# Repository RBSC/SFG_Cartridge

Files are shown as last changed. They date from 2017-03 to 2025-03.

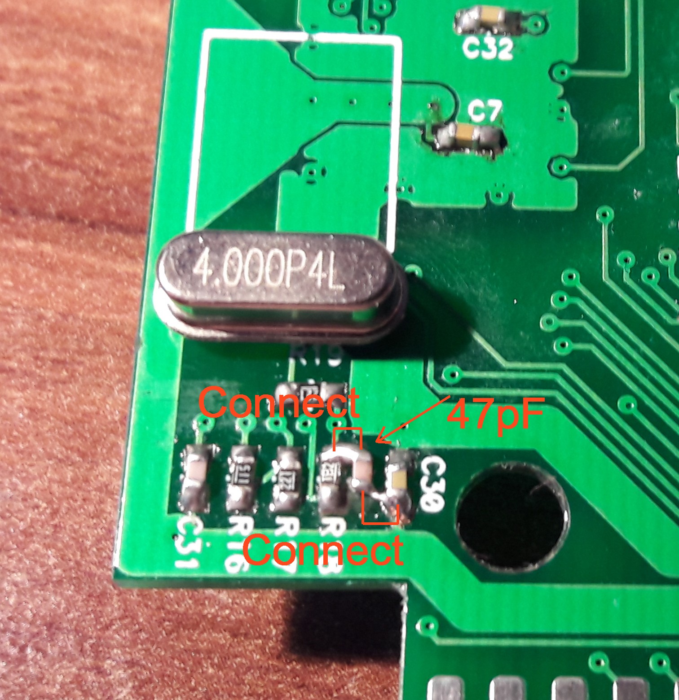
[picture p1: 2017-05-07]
Pics/74HCT04_fix_cart.jpg

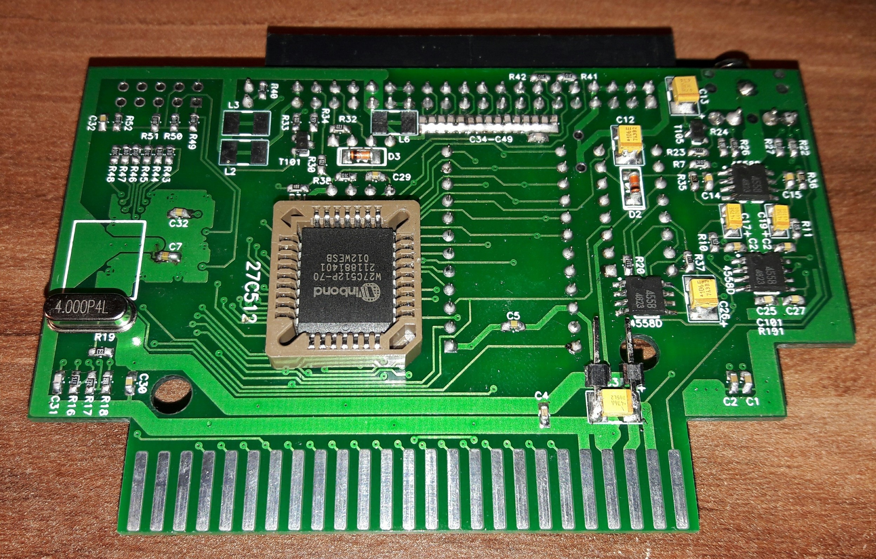
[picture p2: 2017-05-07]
Pics/assembled_cart_back.jpg

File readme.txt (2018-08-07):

Yamaha SFG 05/01-S Cartridge Board v1.2
Copyright (c) 2017 RBSC

The Setup
---------

After assembling, the cartridge needs to be programmed in order to function properly. The following steps are necessary:

 1. Upload the Altera's firmware
 2. Program the BIOS with the provided ROM file

How to upload the firmware
--------------------------

The below instructions are for programming the Altera chip.

 1. Solder jumper pins both sides of C3 capacitor (only for older boards without power connector)
 2. Prepare the ByteBlaster 2 programmer, open the Quartus II software, keep default JTAG selection
 3. Supply 5v power to the cartridge board via jumper pins (mind the correct polarity!)
 4. Connect the ByteBlaster's cable to the AS socket of the cartridge (make sure you connect the cable correctly!)
 5. Click "Autodetect" in Quartus II software, the Altera chip should be found and ready for programming
 6. Use "Change file" option and select the .POF file from the "Firmware" directory
 7. Enable the checkboxes: "Program/Configure", "Verify" and "Blank Check"
 8. Click "Start" and monitor the programming and verification process

If the programming completed successfully, disconnect the ByteBlaster's cable and 5v power from the board.

You must also write the provided ROM file from BIOS directory into the W27C512 EEPROM chip (PLCC32) using any EEPROM programmer.
The ROM file contains 2 different BIOS versions that can be selected by the special jumper on the board.

Using the extension board
-------------------------

The separate extension board was created for the SFG cartridge in order to make available standard SFG sockets - left and right
RCA audio sockets, music keyboard socked and MIDI IN and MIDI OUT sockets. The board can be either mounted on top of the
cartridge or it can be connected to the cartridge with the standard IDE ribbon cable.

IMPORTANT! When connecting the ribbon cable or plugging the extension board on top of the cartridge please make sure that you are
connecting correctly, otherwise damage may occur to your SFG cartridge!

Starting SFG BIOS
-----------------

To start the built-in SFG BIOS make sure that Basic is loaded and type "_musica" or "call musica" without quotes and press Enter.
The BIOS should start immediately. Depending on whether the jumper is installed or not, either the SFG-01 BIOS or SFG-05 BIOS will
be launched. To exit from BIOS software just reboot your MSX.

Notes
-----

If you are using 74HCT04 chip instead of 74LS04 please make sure you add one additional 47pf capacitor. See the 74HCT04_fix_cart.jpg
image for capacitor mounting instructions. This picture shows the placing of an additional capacitor on the board version 1.0. Later
versions of the board have the dedicated place for this capacitor (C50).

IMPORTANT!
----------

The RBSC provides all the files and information for free, without any liability (see the disclaimer.txt file). The provided information,
software or hardware must not be used for commercial purposes unless permitted by the RBSC. Producing a small amount of bare boards for
personal projects and selling the rest of the batch is allowed without the permission of RBSC.

When the sources of the tools are used to create alternative projects, please always mention the original source and the copyright!

Contact information
-------------------

The members of RBSC group Wierzbowsky, Ptero and DJS3000 can be contacted via the MSX.ORG or ZX-PK.RU forums. Just send a personal
message and state your business.

The RBSC repository can be found here:

https://github.com/rbsc

-= ! MSX FOREVER ! =-

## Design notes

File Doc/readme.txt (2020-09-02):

Yamaha SFG 05/01-S Cartridge Board v1.2
Copyright (c) 2017-2020 RBSC

The Setup
---------

After assembling, the cartridge needs to be programmed in order to function properly. The following steps are necessary:

 1. Upload the Altera's firmware
 2. Program the BIOS with the provided ROM file

How to upload the firmware
--------------------------

The below instructions are for programming the Altera chip.

 1. Solder jumper pins both sides of C3 capacitor (only for older boards without power connector)
 2. Prepare the ByteBlaster 2 programmer, open the Quartus II software, keep default JTAG selection
 3. Supply 5v power to the cartridge board via jumper pins (mind the correct polarity!)
 4. Connect the ByteBlaster's cable to the AS socket of the cartridge (make sure you connect the cable correctly!)
 5. Click "Autodetect" in Quartus II software, the Altera chip should be found and ready for programming
 6. Use "Change file" option and select the .POF file from the "Firmware" directory
 7. Enable the checkboxes: "Program/Configure", "Verify" and "Blank Check"
 8. Click "Start" and monitor the programming and verification process

If the programming completed successfully, disconnect the ByteBlaster's cable and 5v power from the board.

You must also write the provided ROM file from BIOS directory into the W27C512 EEPROM chip (PLCC32) using any EEPROM programmer.
The ROM file contains 2 different BIOS versions that can be selected by the special jumper on the board.

Using the extension board
-------------------------

The separate extension board was created for the SFG cartridge in order to make available standard SFG sockets - left and right
RCA audio sockets, music keyboard socked and MIDI IN and MIDI OUT sockets. The board can be either mounted on top of the
cartridge or it can be connected to the cartridge with the standard IDE ribbon cable.

IMPORTANT! When connecting the ribbon cable or plugging the extension board on top of the cartridge please make sure that you are
connecting correctly, otherwise damage may occur to your SFG cartridge!

Starting SFG BIOS
-----------------

To start the built-in SFG BIOS make sure that Basic is loaded and type "_musica" or "call musica" without quotes and press Enter.
The BIOS should start immediately. Depending on whether the jumper is installed or not, either the SFG-01 BIOS or SFG-05 BIOS will
be launched. To exit from BIOS software just reboot your MSX.

Notes
-----

If you are using 74HCT04 chip instead of 74LS04 please make sure you add one additional 47pf capacitor. See the 74HCT04_fix_cart.jpg
image for capacitor mounting instructions. This picture shows the placing of an additional capacitor on the board version 1.0. Later
versions of the board have the dedicated place for this capacitor (C50).

IMPORTANT!
----------

The RBSC provides all the files and information for free, without any liability (see the disclaimer.txt file). The provided information,
software or hardware must not be used for commercial purposes unless permitted by the RBSC. Producing a small amount of bare boards for
personal projects and selling the rest of the batch is allowed without the permission of RBSC.

When the sources of the tools are used to create alternative projects, please always mention the original source and the copyright!

Contact information
-------------------

The members of RBSC group Tnt23, Wierzbowsky, Pencioner, Ptero, GreyWolf, SuperMax and DJS3000 can be contacted via the group's e-mail
address:

info@rbsc.su

The group's coordinator could be reached via this e-mail address:

admin@rbsc.su

The group's website can be found here:

https://rbsc.su/
https://rbsc.su/ru

The RBSC's hardware repository can be found here:

https://github.com/rbsc

The RBSC's 3D model repository can be found here:

https://www.thingiverse.com/groups/rbsc/things

-= ! MSX FOREVER ! =-

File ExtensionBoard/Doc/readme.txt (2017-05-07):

Yamaha SFG 05/01-S Cartridge Extension Board v1.0
Copyright (c) 2017 RBSC

About
-----

The separate extension board was created for the SFG cartridge in order to make available standard SFG sockets - left and right
RCA audio sockets, music keyboard socked and MIDI IN and MIDI OUT sockets. The board can be either mounted on top of the
cartridge or it can be connected to the cartridge with the standard IDE ribbon cable.

IMPORTANT! When connecting the ribbon cable or plugging the extension board on top of the cartridge please make sure that you are
connecting correctly, otherwise damage may occur to your SFG cartridge! Don't solder the straight pin male IDE connector to the
place where the IDE angled pin female connector should be soldered. The pins of those 2 connectors are vertically reversed! The
IDE ribbon cable must be connected only to the straight pin male connector on the extension board.

IMPORTANT!
----------

The RBSC provides all the files and information for free, without any liability (see the disclaimer.txt file). The provided information,
software or hardware must not be used for commercial purposes unless permitted by the RBSC. Producing a small amount of bare boards for
personal projects and selling the rest of the batch is allowed without the permission of RBSC.

When the sources of the tools are used to create alternative projects, please always mention the original source and the copyright!

Contact information
-------------------

The members of RBSC group Wierzbowsky, Ptero and DJS3000 can be contacted via the MSX.ORG or ZX-PK.RU forums. Just send a personal
message and state your business.

The RBSC repository can be found here:

https://github.com/rbsc

-= ! MSX FOREVER ! =-

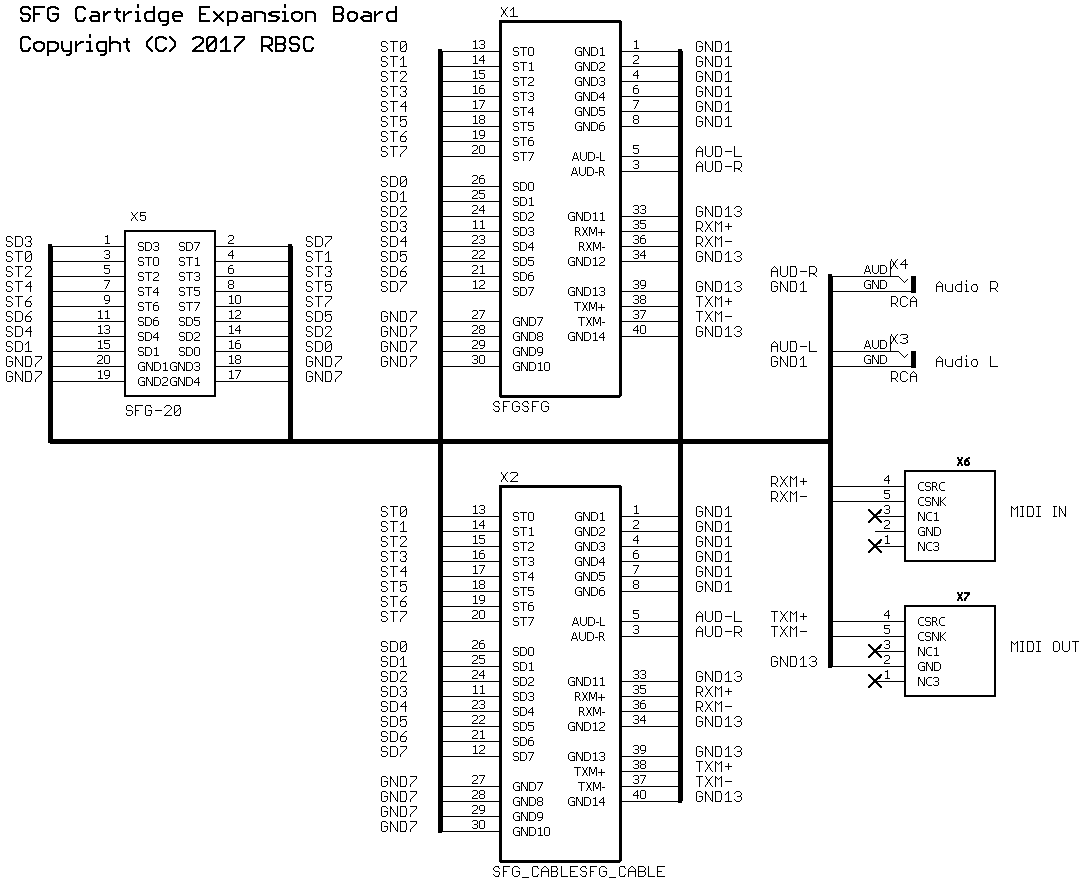
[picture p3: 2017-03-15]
ExtensionBoard/Doc/schematics.png

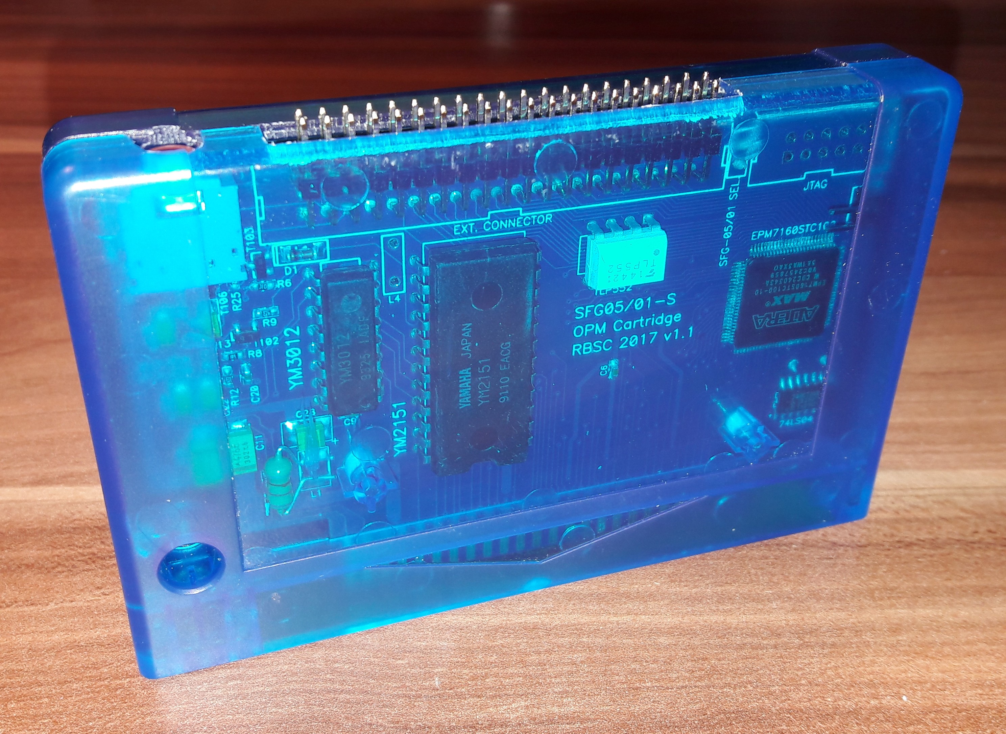
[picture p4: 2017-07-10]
Pics/cart_case.jpg

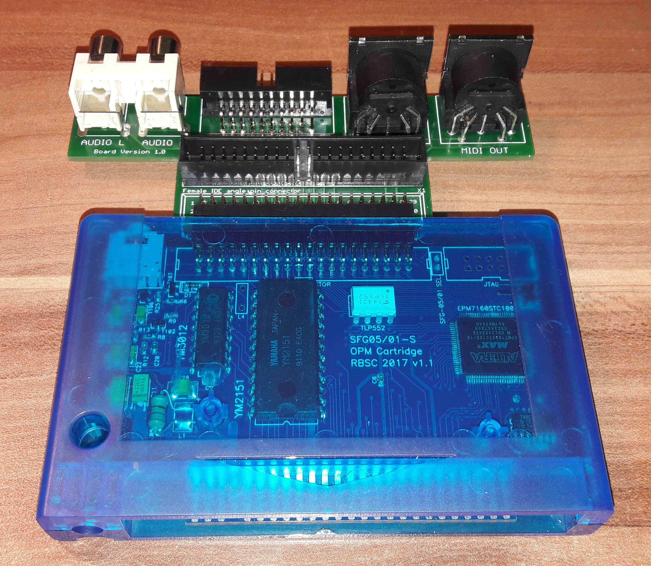
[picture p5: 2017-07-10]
Pics/cart_with_adapter.jpg

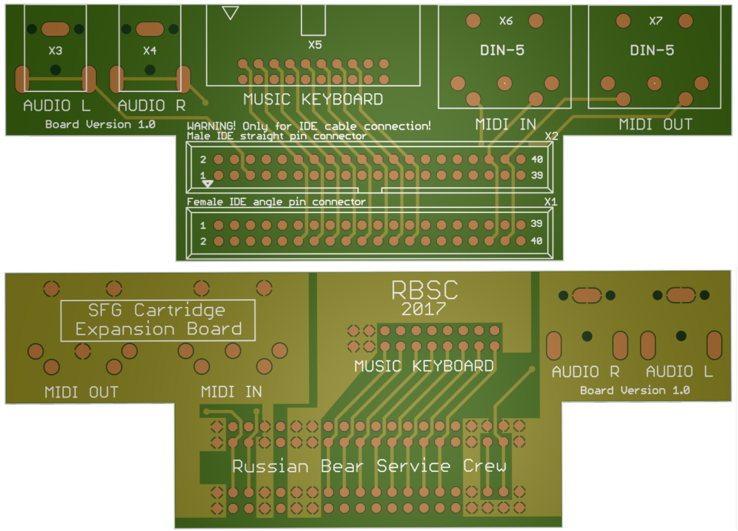
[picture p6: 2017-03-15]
ExtensionBoard/Pics/board.jpg

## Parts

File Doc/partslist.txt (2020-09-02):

SFG 05/01-S OPM Cartridge Version 1.2
Copyright (C) 2017-2020 RBSC
Original SFG design by Yamaha Corp.

IMPORTANT!
On the board version 1.0 (on this board the version number may be missing) the R34 and R33 resistors' numbers
are swapped. So the 220 Ohm resistor should be must on the pads marked as R34 and the 4.7 kOhm resistor must
be soldered on the pads marked as R33.

Partslist
---------

Count  ComponentName   RefDes          PatternName     Value           Notes
------ --------------- --------------- --------------- --------------- ---------------

     3 1N4148S         D1              SOD80PD                         SMD diode
                       D2                                                                             
                       D3                                                                             
     3 4558D           AU1             SOP8                            Amplifier
                       AU2                                                                            
                       AU3                                                                            
     1 C_0603          C20             C0603_132A      0.027           
    11 C_0603          C1              C0603_132A      0.1             
                       C2                                                                             
                       C4                                                                             
                       C5                                                                             
                       C6                                                                             
                       C7                                                                             
                       C9                                                                             
                       C29                                                                            
                       C30                                                                            
                       C32                                                                            
                       C33                                                                            
     2 C_0603          C25             C0603_132A      1n              
                       C27                                                                            
     2 C_0603          C21             C0603_132A      1n8             
                       C23                                                                            
     1 C_0603          C50             C0603_132A      47pF             Only for 74HCT04 option!
    17 C_0603          C31             C0603_132A      100pF            
                       C34                                                                            
                       C35                                                                            
                       C36                                                                            
                       C37                                                                            
                       C38                                                                            
                       C39                                                                            
                       C40                                                                            
                       C41                                                                            
                       C42                                                                            
                       C43                                                                            
                       C44                                                                            
                       C45                                                                            
                       C46                                                                            
                       C47                                                                            
                       C48                                                                            
                       C49                                                                            
     2 C_0603          C14             C0603_132A      390pF            
                       C15                                                                            
     6 C_1206          C16             C1206_134A      4.7uF 25v       
                       C17                                                                            
                       C18                                                                            
                       C19                                                                            
                       C22                                                                            
                       C24                                                                            
     1 C_1812          C12             C1812_136A      10uF 6.3v       
     1 C_1812          C26             C1812_136A      10uF 16v        
     2 C_1812          C3              C1812_136A      47uF 16v        
                       C28                                                                            
     1 C_1812          C13             C1812_136A      47uF 6.3v      
     1 C_1812          L1              C1812_136A      820 uH          Power filter, must-have
     4 C_1812          L2              C1812_136A                      Optional ferrite bead
                       L3                                              Optional ferrite bead
                       L4                                              Optional ferrite bead
                       L5                                              Optional ferrite bead
     1 EPM7160STC100-1 IC103           TQFP100                         Altera MAX
     1 IDC2X20M        CN4             IDC40M                          Angled male IDE connector
     1 IDC10M          CN3             IDC10M                          JTAG connector
     1 M27C512         IC104           PLCC32                          EPROM/EEPROM, also 27C256 possible
     6 R_0603          R26             R0603_101A      1k              
                       R27                                                                            
                       R49                                                                            
                       R50                                                                            
                       R51                                                                            
                       R52                                                                            
     1 R_0603          R18             R0603_101A      1k8             
     1 R_0603          R8              R0603_101A      1M              
     2 R_0603          R22             R0603_101A      1.8k            
                       R24                                                                            
     1 R_0603          R23             R0603_101A      2k2             
     2 R_0603          R21             R0603_101A      2.2k            
                       R25                                                                            
     4 R_0603          R9              R0603_101A      4k7             
                       R12                                                                            
                       R14                                                                            
                       R34                                                                            
     2 R_0603          R10             R0603_101A      4.7k            
                       R11                                                                            
    14 R_0603          R6              R0603_101A      10k             
                       R7                                                                             
                       R13                                                                            
                       R15                                                                            
                       R38                                                                            
                       R40                                                                            
                       R41                                                                            
                       R42                                                                            
                       R43                                                                            
                       R44                                                                            
                       R45                                                                            
                       R46                                                                            
                       R47                                                                            
                       R48                                                                            
     2 R_0603          R35             R0603_101A      22k             
                       R36                                                                            
     7 R_0603          R4              R0603_101A      220             
                       R5                                                                             
                       R17                                                                            
                       R19                                                                            
                       R30                                                                            
                       R32                                                                            
                       R33                                                                            
     1 R_0603          R31             R0603_101A      330             
     1 R_0603          R37             R0603_101A      390             
     2 R_0603          R16             R0603_101A      560             
                       R20                                                                            
     1 SN74ALS04BD     IC108           D014                            SMD chip. See readme for 74HCT04 option
     1 SOT-23(A1A2K)   T3              SOT-23(A1A2K)   2SA733          
     5 SOT-23(A1A2K)   T1              SOT-23(A1A2K)   2SC945          
                       T2                                                                          
                       T4                                                                          
                       T5                                                                          
                       T6                                                                          
     1 ST-222          AX1             ST-222                          Audio socket
     2 TANTAL-C        C10             C-TANTAL-C      100uF 16v
                       C11                                                                            
     1 TLP552          IC109           TLP552                          DIP casing
     1 YM2151          IC101           YM2151                          DIP casing
     1 YM3012          IC102           YM3012                          DIP casing

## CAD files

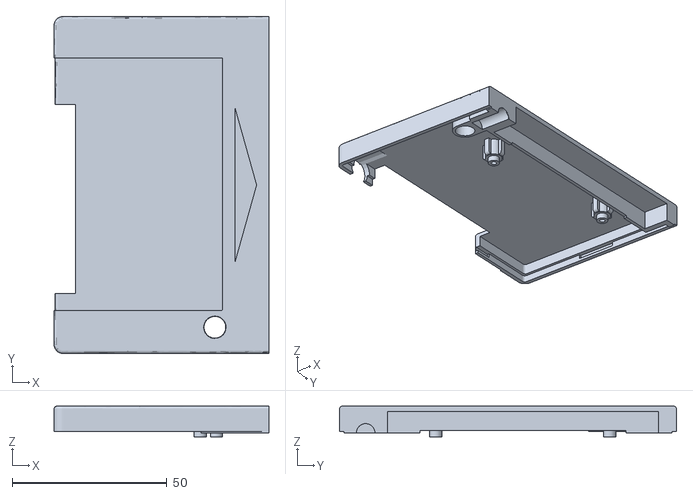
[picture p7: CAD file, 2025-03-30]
Case/SFG_Case_part2_1.2.stl
69.5 x 109.0 x 9.95

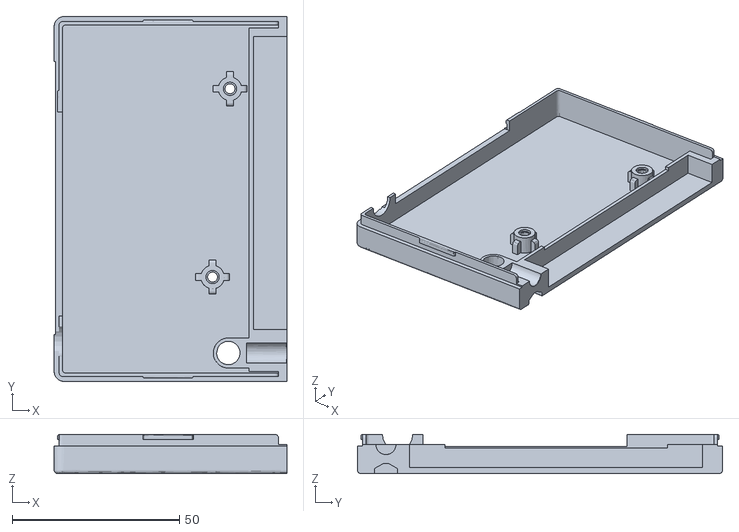
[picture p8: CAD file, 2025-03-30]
Case/SFG_Case_part1_1.2.stl
69.5 x 109.0 x 11.6

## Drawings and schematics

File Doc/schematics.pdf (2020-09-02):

# MSX SFG 05/01-S Cartridge Vers. 1.2

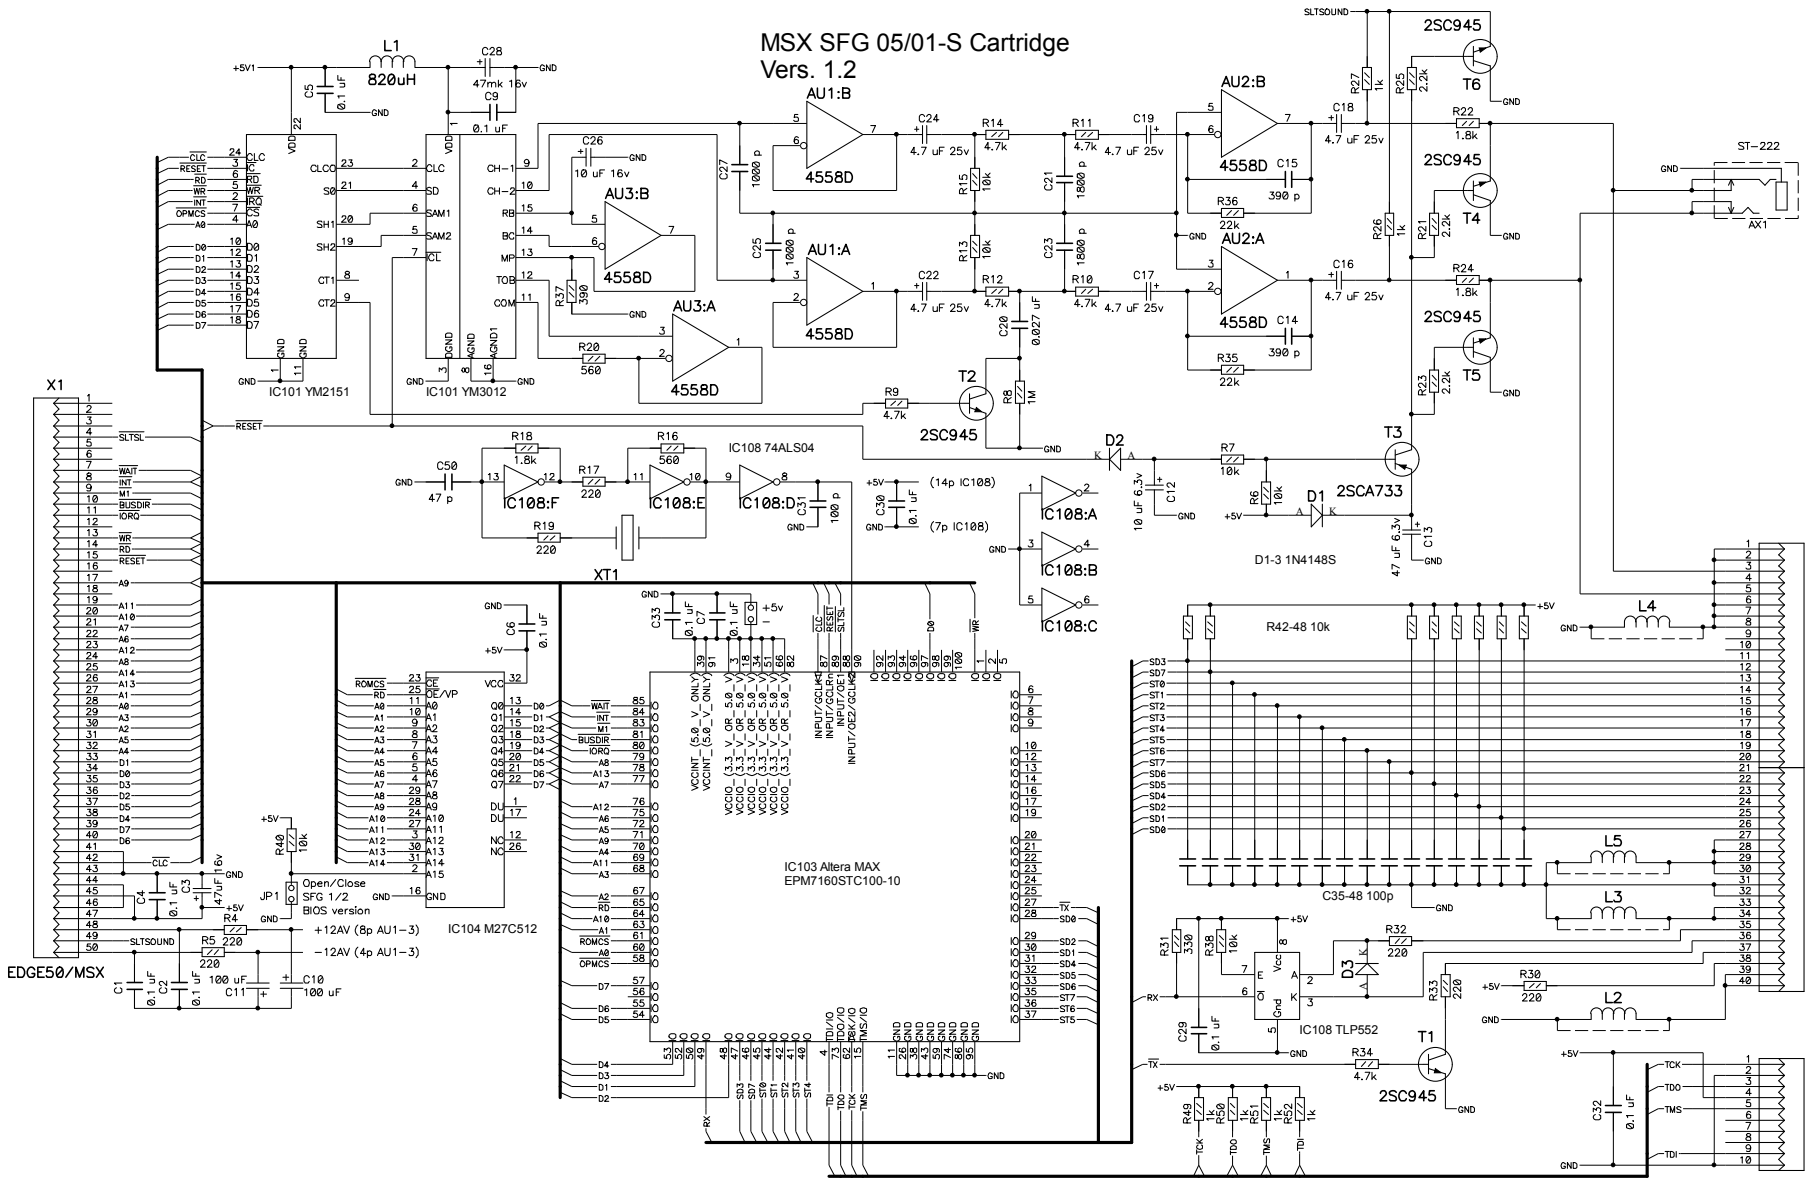
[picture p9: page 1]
IC108 74ALS04; IC108 TLP552; IC103 Altera MAX EPM7160STC100-10

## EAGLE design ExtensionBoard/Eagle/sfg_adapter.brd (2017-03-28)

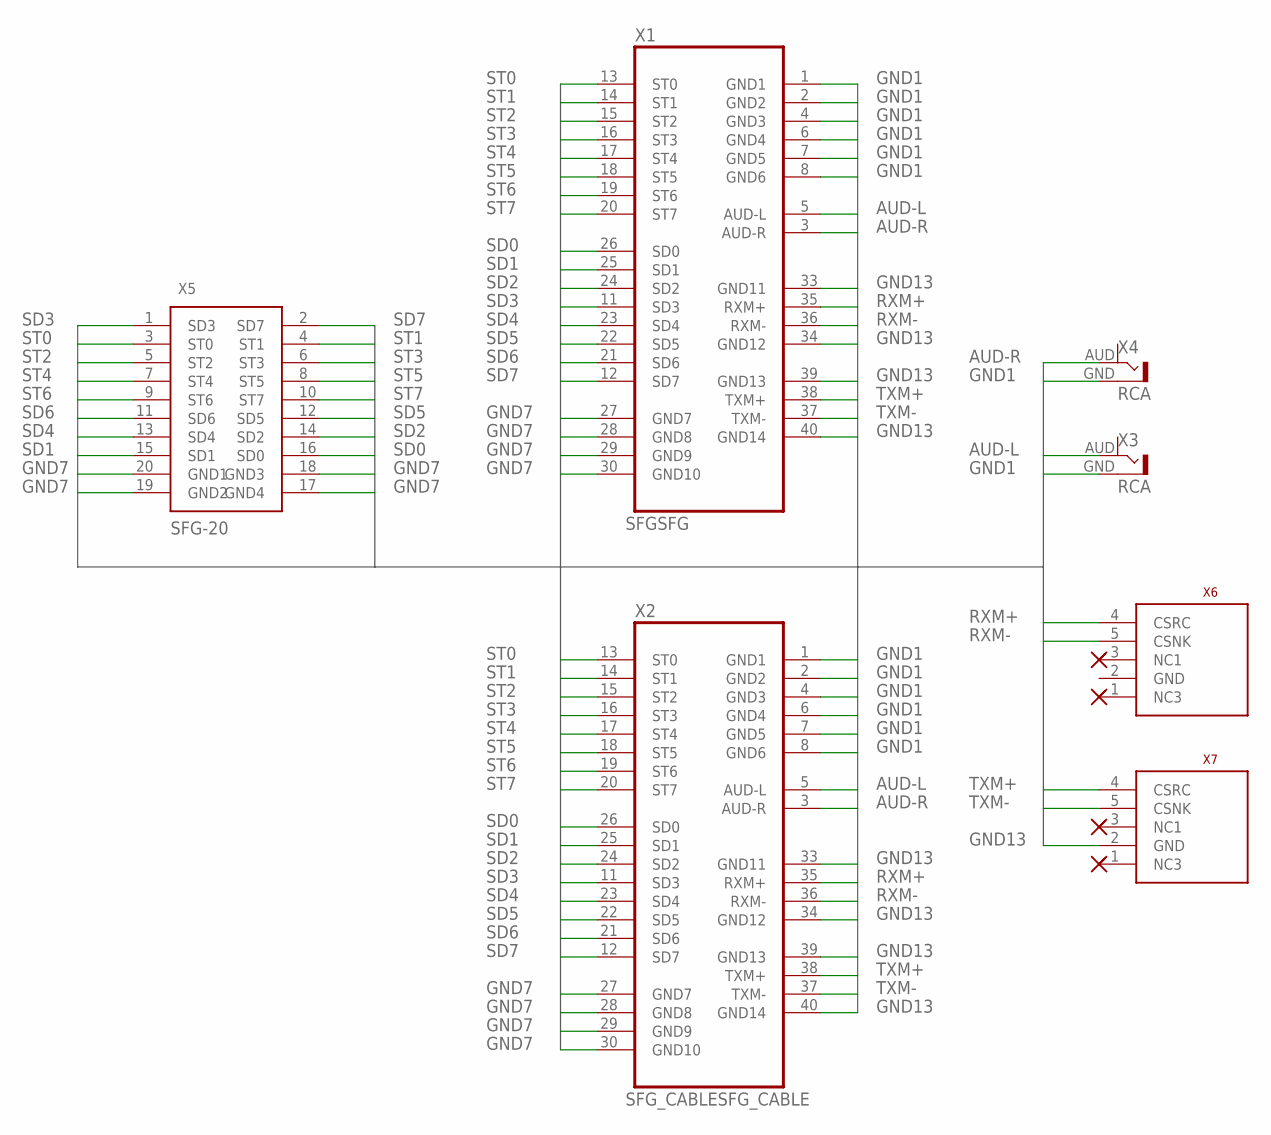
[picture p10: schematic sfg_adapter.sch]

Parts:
X1: SFGSFG; SFG
X2: SFG_CABLESFG_CABLE; SFG_CABLE
X3, X4: RCA
X5: SFG-20
X6, X7: MIDI_CONN_FEMALE_SUPPORT; DIN_5_FEMALE_SUPPORT

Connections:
AUD-L: X1.5 (AUD-L), X2.5 (AUD-L), X3.AUD
AUD-R: X1.3 (AUD-R), X2.3 (AUD-R), X4.AUD
GND1: X1.1 (GND1), X1.2 (GND2), X1.4 (GND3), X1.6 (GND4), X1.7 (GND5), X1.8 (GND6), X2.1 (GND1), X2.2 (GND2), X2.4 (GND3), X2.6 (GND4), X2.7 (GND5), X2.8 (GND6), X3.GND (GND1), X4.GND (GND1)
GND7: X1.27 (GND7), X1.28 (GND8), X1.29 (GND9), X1.30 (GND10), X2.27 (GND7), X2.28 (GND8), X2.29 (GND9), X2.30 (GND10), X5.17 (GND4), X5.18 (GND3), X5.19 (GND2), X5.20 (GND1)
GND13: X1.33 (GND11), X1.34 (GND12), X1.39 (GND13), X1.40 (GND14), X2.33 (GND11), X2.34 (GND12), X2.39 (GND13), X2.40 (GND14), X7.2 (GND)
RXM+: X1.35 (RXM+), X2.35 (RXM+), X6.4 (CSRC)
RXM-: X1.36 (RXM-), X2.36 (RXM-), X6.5 (CSNK)
SD0: X1.26 (SD0), X2.26 (SD0), X5.16 (SD0)
SD1: X1.25 (SD1), X2.25 (SD1), X5.15 (SD1)
SD2: X1.24 (SD2), X2.24 (SD2), X5.14 (SD2)
SD3: X1.11 (SD3), X2.11 (SD3), X5.1 (SD3)
SD4: X1.23 (SD4), X2.23 (SD4), X5.13 (SD4)
SD5: X1.22 (SD5), X2.22 (SD5), X5.12 (SD5)
SD6: X1.21 (SD6), X2.21 (SD6), X5.11 (SD6)
SD7: X1.12 (SD7), X2.12 (SD7), X5.2 (SD7)
ST0: X1.13 (ST0), X2.13 (ST0), X5.3 (ST0)
ST1: X1.14 (ST1), X2.14 (ST1), X5.4 (ST1)
ST2: X1.15 (ST2), X2.15 (ST2), X5.5 (ST2)
ST3: X1.16 (ST3), X2.16 (ST3), X5.6 (ST3)
ST4: X1.17 (ST4), X2.17 (ST4), X5.7 (ST4)
ST5: X1.18 (ST5), X2.18 (ST5), X5.8 (ST5)
ST6: X1.19 (ST6), X2.19 (ST6), X5.9 (ST6)
ST7: X1.20 (ST7), X2.20 (ST7), X5.10 (ST7)
TXM+: X1.38 (TXM+), X2.38 (TXM+), X7.4 (CSRC)
TXM-: X1.37 (TXM-), X2.37 (TXM-), X7.5 (CSNK)

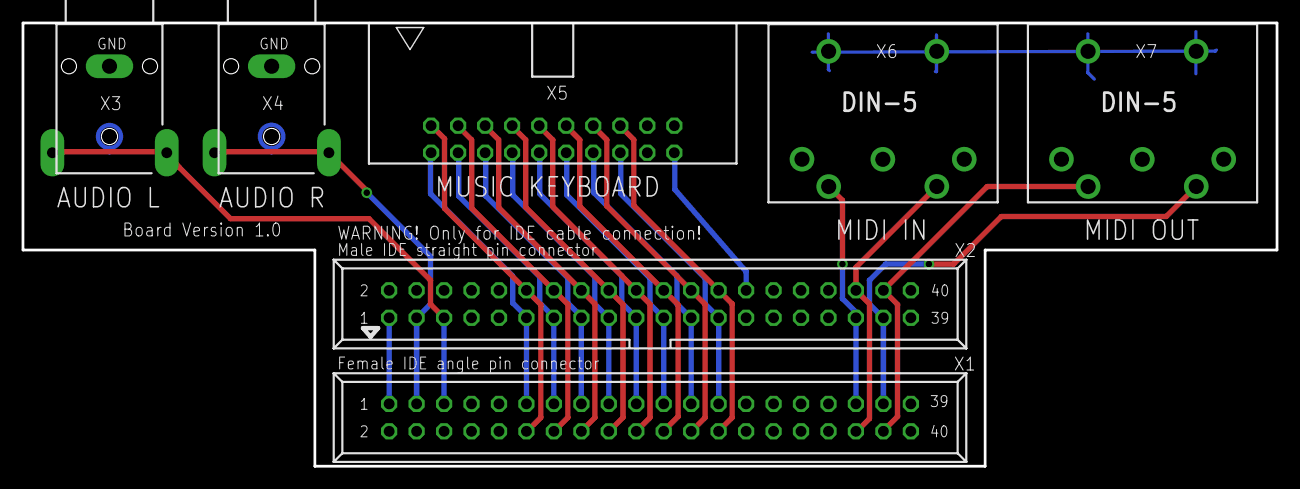
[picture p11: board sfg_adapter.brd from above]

Board: 2 copper layers, 116.0 x 41.0 mm, 7 parts (0 on the bottom side), 25 nets.

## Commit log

2017-03-15 Expansion board
    Expansion board sources + new pcb of the cartridge
    [sfg_adapter.brd, sfg_adapter.sch]
2017-03-16 New board version
    Fixed 3 layout problems
2017-03-28 New board revision
    New board revision + Gerbers
    [sfg_adapter.brd]
2017-05-07 The sources for v1.0 board and extension board
    [sfg_adapter.brd, sfg_adapter.sch]
2017-07-10 Board updated to version 1.2
    Board updated to version 1.2
2017-07-12 Gerbers v1.2, updated readme and PCB
2018-07-15 Updated 15.07.2018
    Updated partslist, added schematics files
    [sfg_cart.sch]
2018-07-15 Updated 15.07.2018
    Updated schematics
    [sfg_cart.sch]
2020-09-02 Updated 02.09.2020
    Updated the board and schematics. The board now has stop polygons on the
    edge connector. Schematics now has proper values for capacitors. No
    changes in the partslist or functionality were made.
    [sfg_cart.sch]
2020-09-02 Updated 02.09.2020
    Fixed schematics (capacitor values), added stop polygons onto the edge
    connector.
    [sfg_cart.sch]
2025-03-30 Update 30.03.2025
    Published labels and 3D models of the case that were created by Cristiano Gonçalves.
    [SFG_Case_part1_1.2.stl, SFG_Case_part2_1.2.stl]

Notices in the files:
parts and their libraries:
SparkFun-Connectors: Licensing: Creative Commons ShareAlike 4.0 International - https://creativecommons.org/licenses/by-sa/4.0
